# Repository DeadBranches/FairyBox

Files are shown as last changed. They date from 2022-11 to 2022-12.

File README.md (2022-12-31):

# FairyBox

Kicad_board_render

pcbnew_screenshot

### Software
A fork of [LilyTiny TinyTwinkle](https://github.com/deadbranch-forks/LilyTiny_LilyTwinkle)

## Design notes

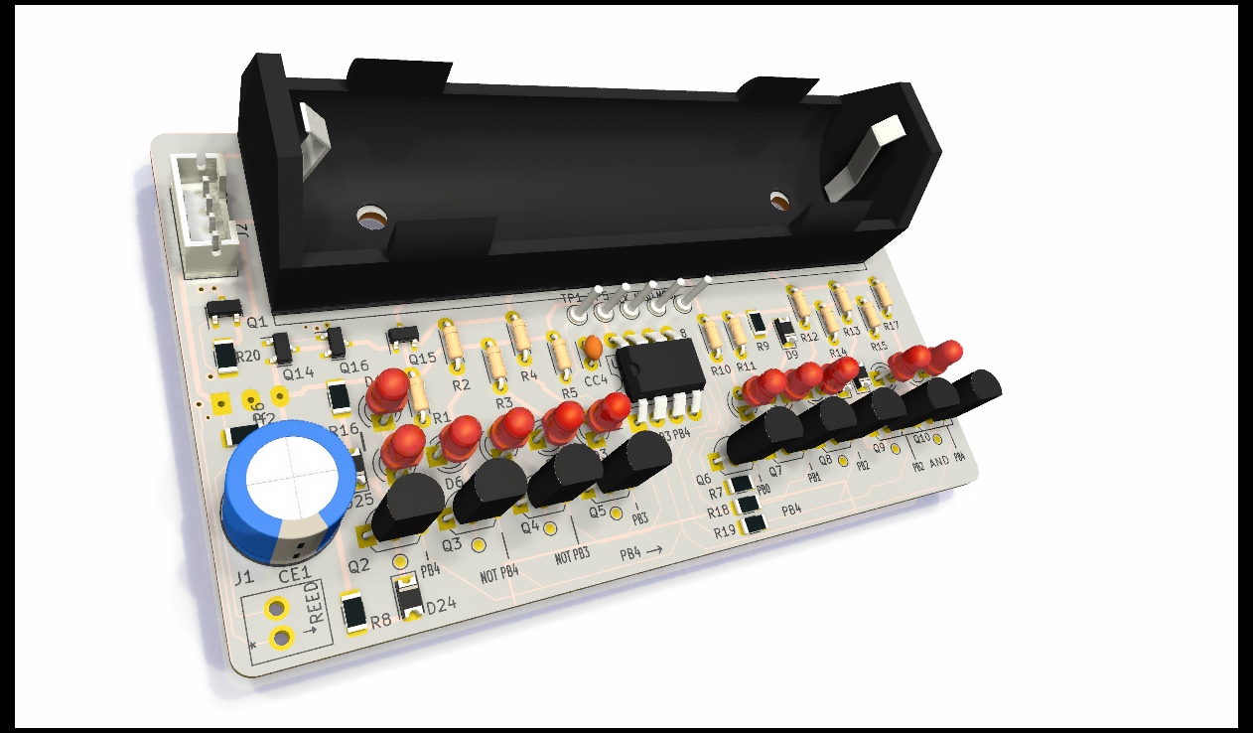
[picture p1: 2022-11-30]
Hardware/Fairybox-render-111022.png

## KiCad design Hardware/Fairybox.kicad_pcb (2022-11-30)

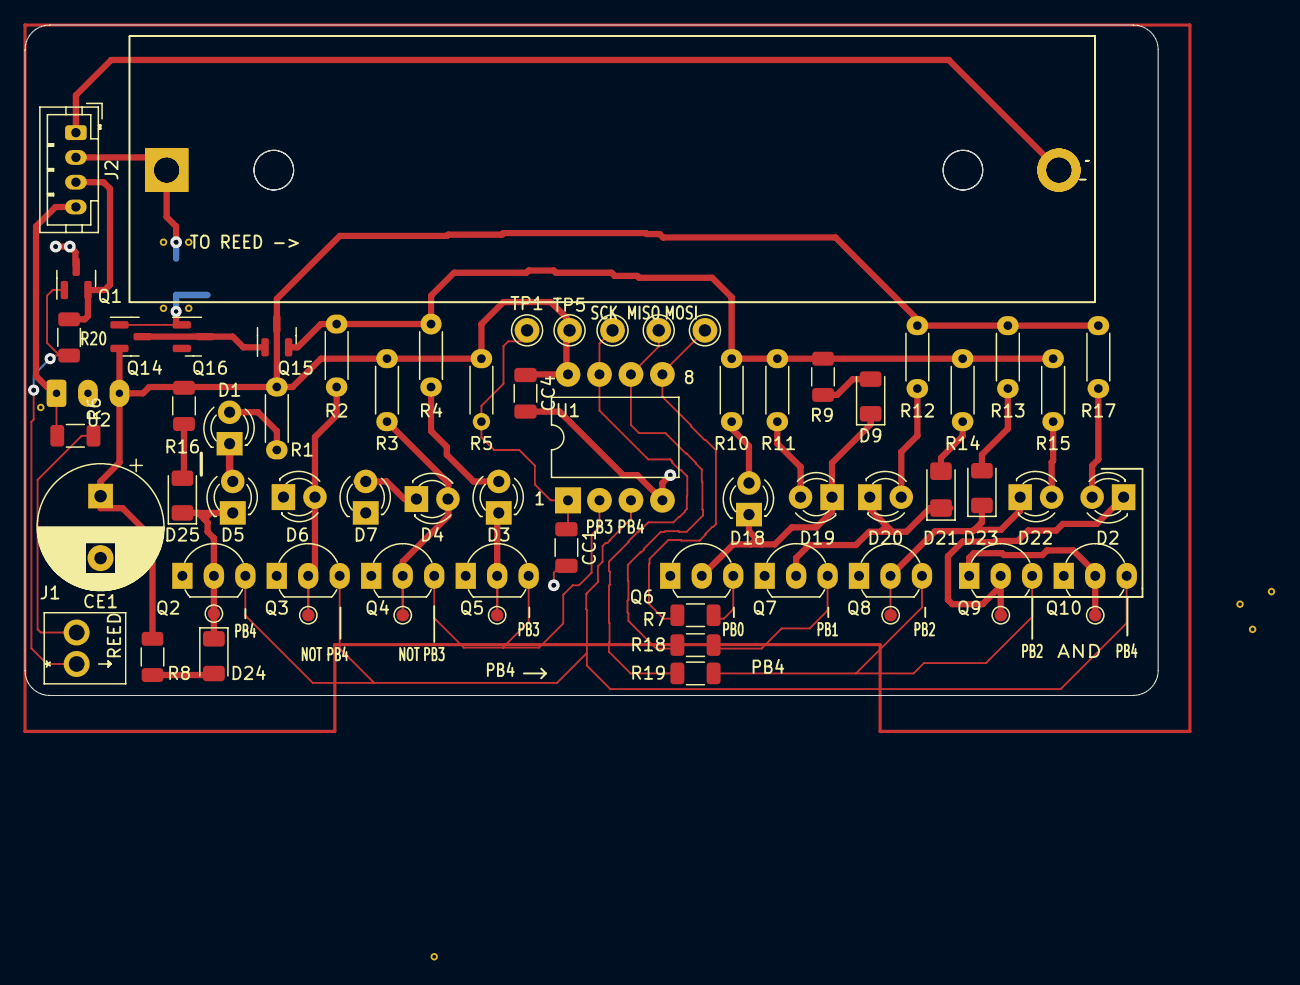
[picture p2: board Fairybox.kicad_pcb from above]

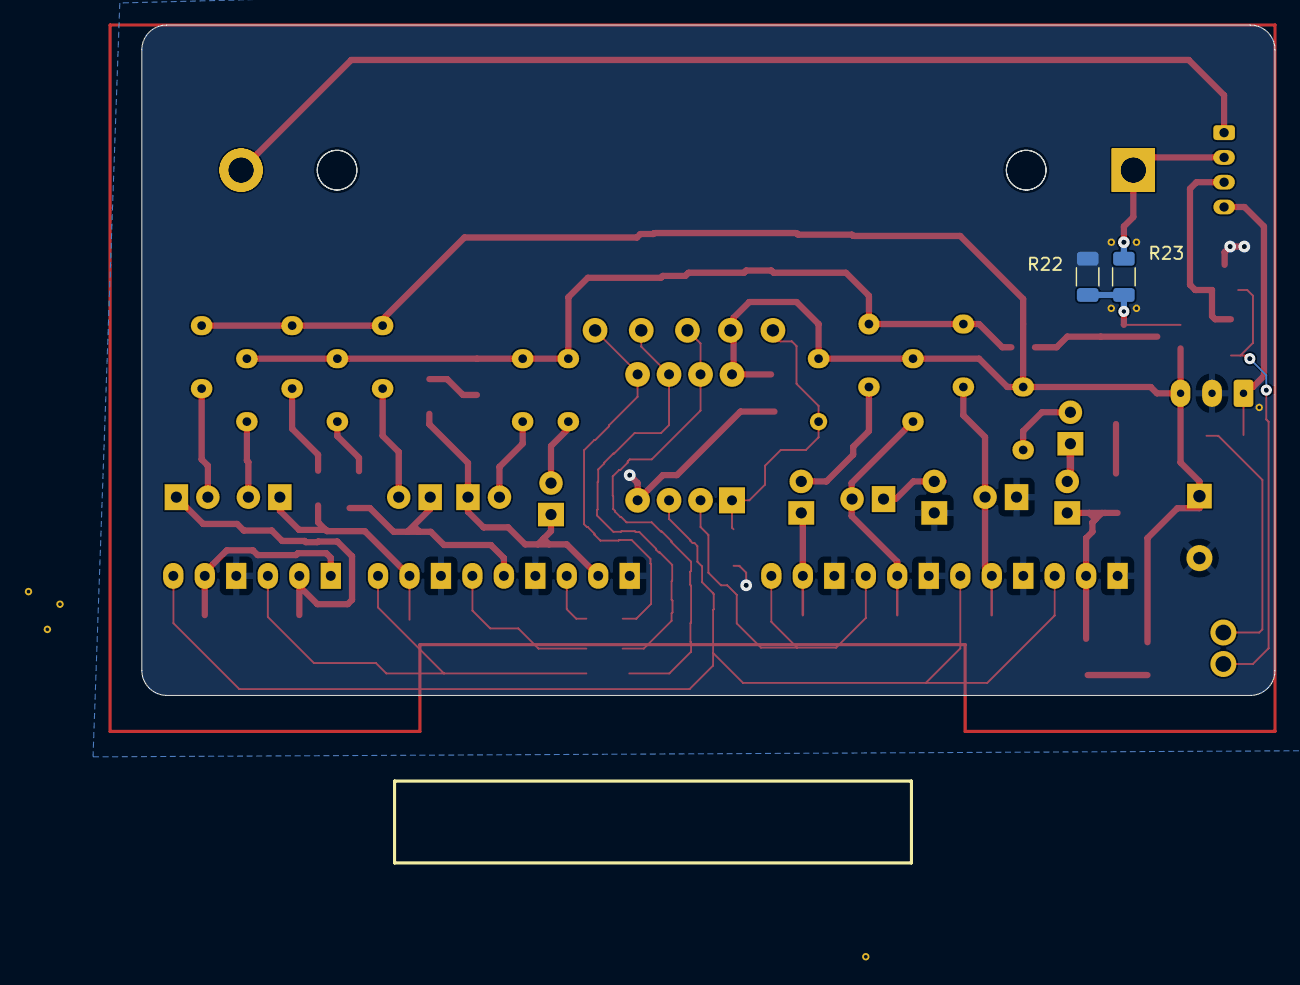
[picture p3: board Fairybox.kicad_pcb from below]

Board: 2 copper layers, 91.4 x 54.1 mm, 81 parts (2 on the bottom side), 43 nets.

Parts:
BAT1, BAT1#2: locked; 18650 battery sled 1x
CC1: 0.22uF; C_1206_3216Metric
CC4: locked; C_1206_3216Metric
CE1: locked; CP_Radial_D10.0mm_P5.00mm
D1, D2, D3, D5, D6, D7, D18, D19, D20, D22: locked; LED_D3.0mm-DRC-larger-silk-footprint
D4: RED; LED_D3.0mm-DRC-larger-silk-footprint
D9, D24: BLUE; D_1206_3216Metric
D21: BLUE; D_1206_3216Metric_Pad1.42x1.75mm_HandSolder
D23, D25: RED; D_1206_3216Metric
J1: REED; KF128-2P
J2: JST B4B-PH-K-S; JST_PH_B4B-PH-K_1x04_P2.00mm_Vertical
JP1, JP3, JP5, JP9: ViaGND; Via-GND
JP2, JP4, JP6, JP7, JP8: ViaGND; PTH-Test_Point
Q1: locked; SOT-23
Q2, Q3, Q4, Q5, Q6, Q7, Q8, Q9, Q10: locked; TO-92L_Inline_Wide
Q14: AO3401A; SOT-23
Q15, Q16: SI2302; SOT-23
R1, R2, R3, R4, R5, R10, R11, R12, R13, R14, R15, R17: locked; R_Axial_DIN0204_L3.6mm_D1.6mm_P5.08mm_Horizontal
R6: 10K; R_1206_3216Metric
R7, R8, R18, R19: 470R; R_1206_3216Metric
R9: ??R; R_1206_3216Metric
R16: locked; R_1206_3216Metric
R20: 100K; R_1206_3216Metric
R22: 1M; R_1206_3216Metric
R23: 330k; R_1206_3216Metric
TP1: RST; Pin_D1.0mm_L10.0mm
TP2: locked; Pin_D1.0mm_L10.0mm
TP3: MISO; Pin_D1.0mm_L10.0mm
TP4: MOSI; Pin_D1.0mm_L10.0mm
TP5: VCC; Pin_D1.0mm_L10.0mm
TP6: TPP; TestPoint_Pad_D1.0mm
TP7: Q3_COL TP; TestPoint_Pad_D1.0mm
TP8: Q2_TP; TestPoint_Pad_D1.0mm
TP9: Q5_COL TP; TestPoint_Pad_D1.0mm
TP10: Q8_COL_TP; TestPoint_Pad_D1.0mm
TP11: Q9_COL_TP; TestPoint_Pad_D1.0mm
TP12: Q10_COL_TP; TestPoint_Pad_D1.0mm
U1: ATTINY85; DIP-8_W10.16mm
U2: locked; 3p-P2.54mm-big-pad-wire-holes

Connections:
+5V: CC4.1, CE1.1, Q14.2 (S), Q15.3 (D), R1.1, R3.1, R5.2, R8.1, R12.1, R13.1, R16.1, R17.1, TP5.1, U1.8 (VCC), U2.3 (VOUT)
/+5V B-LED: Q15.2 (S), R2.1, R4.1, R9.1, R10.1, R11.1, R14.1, R15.1
/CHARGE BOARD OUT B+: J2.4, R6.2, U2.1 (VIN)
/CHARGE BOARD OUT B-: J2.3, Q1.2 (S), R20.1
/D1_AN: D1.2 (A), R1.2
/D2_AN: D2.2 (A), R17.2
/D3_AN: D3.2 (A), R4.2
/D5_AN: D1.1 (K), D5.2 (A)
/D6_AN: D6.2 (A), Q3.2 (C), R2.2, TP7.1
/D7_AN: D4.1 (K), D7.2 (A)
/D9_AN: D9.2 (A), R9.2
/D18_AN: D18.2 (A), R10.2
/D19_AN: D19.2 (A), R11.2
/D20_AN: D20.2 (A), R12.2
/D21_AN: D22.2 (A), R15.2
/D22_AN: D21.2 (A), R14.2
/D23_AN: D23.2 (A), R13.2
/D24_AN: D24.2 (A), R8.2
/D25_AN: D25.2 (A), R16.2
/LBAT_NOT: Q14.1 (G), Q16.1 (G), R22.1, R23.2
/LI-ION_NEG: BAT1.2 (-), BAT1#2.2 (-), J2.2
/LI-ION_POS: BAT1.1 (+), BAT1#2.1 (+), J2.1, R22.2
/MCU GPIO0 MOSI: Q6.3 (B), R7.2
/MCU GPIO1 MISO: Q7.3 (B), R18.2
/MCU GPIO2 SCK: Q8.3 (B), Q9.3 (B), R19.2
/MCU GPIO3: Q4.3 (B), Q5.3 (B), U1.2 (PB3)
/MCU GPIO4: Q2.3 (B), Q3.3 (B), Q10.3 (B), U1.3 (PB4)
/MCU RST: CC1.1, R5.1, TP1.1, U1.1 (RST)
/PB0 PHY: R7.1, TP4.1, U1.5 (PB0)
/PB1 PHY: R18.1, TP3.1, U1.6 (PB1)
/PB2 PHY: R19.1, TP2.1, U1.7 (PB2)
/Q1_GATE: J1.2, Q1.1 (G), R20.2
/Q2_COL: D5.1 (K), D24.1 (K), D25.1 (K), Q2.2 (C), TP8.1
/Q4_COL: D4.2 (A), Q4.2 (C), R3.2, TP6.1
/Q5_COL: D3.1 (K), Q5.2 (C), TP9.1
/Q6_COL: D9.1 (K), D18.1 (K), D19.1 (K), Q6.2 (C)
/Q7_COL: D20.1 (K), D21.1 (K), Q7.2 (C)
/Q8_COL: D22.1 (K), D23.1 (K), Q8.2 (C), TP10.1
/Q9_COL: D2.1 (K), Q9.2 (C), TP11.1
/Q10_COL: Q9.1 (E), Q10.2 (C), TP12.1
/Q15_COL: Q14.3 (D), Q15.1 (G), Q16.3 (D)
/REED_IN: J1.1, R6.1
GND: CC1.2, CC4.2, CE1.2, D6.1 (K), D7.1 (K), JP1.1 (GND), JP2.1 (GND), JP3.1 (GND), JP4.1 (GND), JP5.1 (GND), JP6.1 (GND), JP7.1 (GND), JP8.1 (GND), JP9.1 (GND), Q1.3 (D), Q2.1 (E), Q3.1 (E), Q4.1 (E), Q5.1 (E), Q6.1 (E), Q7.1 (E), Q8.1 (E), Q10.1 (E), Q16.2 (S), R23.1, U2.2 (GND)

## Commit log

2022-10-16 GPIO Assignment Changes
    In order to enable more efficient signal trace routing transistor base pins were reassigned to different MCU signal pins. The new order no longer has signal traces crossing paths to get to their destination. In other words, it's eliminated the need for any vias to the ground plane.
    This routing is much simpler and improves the chances of a successful (functioning) PCB.
    - Easier to manufacture. Not pushing JLCPCB's manufacturing capabilities is a good thing.
    - Likely less unintended EMI radiation.
    - Less opportunities for signal crosstalk.
    [fairybox.kicad_sch]
2022-10-16 MCU reset pin and resistor fix
    Attiny85 Reset Pin
    - Rotated pull-up resistor R5. 5V pad now faces north.
    - Extended 5V copper pour to include R5
    [fairybox.kicad_pcb]
2022-10-16 Eliminating Q10_COL via
    Re-routed Q9_COL around Q9 to eliminate the need for the Q10_COL net via.
    [fairybox.kicad_pcb]
2022-10-16 Removed bulk capacitor power puddle
    Replaced CE1<>U2 copper pour with a 0.600mm track.
    [fairybox.kicad_pcb]
2022-10-17 Updated solder mask labels
    Moved component reference designators around. Added some informational text to the solder mask
    [fairybox.kicad_pcb]
2022-10-19 Cleanup
    alignment and other misc changes.
    [fairybox.kicad_pcb]
2022-10-19 Adding kicad project files
    [Fairybox.kicad_pcb, Fairybox.kicad_sch]
2022-10-19 Testing kicad/github interoperability
    [Fairybox.kicad_sch]
2022-10-19 Testing kicad/github interoperability v2
    [Fairybox.kicad_sch]
2022-10-20 Testing how symlinks interact with git. FairyBoxTest.ino is a symlink to the ArduinoIDE sketch folder elsewhere on the drive.
2022-10-20 testing symlinks. Updated /f/c/code - arduino sketchbooks/fairybox - branch_main/fairybox - branch_main.ino with a comment. Seeing if giit picks it up.
2022-10-21 Testing git and ArduinoIDE links. File in arduino sketch folder is a symlink to local git repo. With ArduinoIDE, opened sketch, made a change, saved. Git picked up the change. Pushing it to remote re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
2022-10-21 Misc changes I forget
    [Fairybox.kicad_pcb, Fairybox.kicad_sch]
2022-10-21 Removing relocated kicad project files.
    [fairybox.kicad_pcb, fairybox.kicad_sch]
2022-10-24 Misc hardware changes
    [Fairybox.kicad_pcb, Fairybox.kicad_sch]
2022-10-24 Update Fairybox.kicad_pro
    Sync with local
2022-10-24 Update Fairybox.kicad_sch
    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
    [Fairybox.kicad_sch]
2022-10-25 Updated testpoints and silkscreen
    [Fairybox.kicad_pcb, Fairybox.kicad_sch]
2022-10-27 PCB layout tweaks
    [Fairybox.kicad_pcb]
2022-10-28 Power Delivery EEschema - Added two 1x2P 2.5mm pitch pin header symbols with associated footprints to replace the custom liion charge breakout board symbol/footprints - Moved liion charge board and n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
    MCU
    EEschema
    - Added 220R series resistors (R7, R18, R19) to each MCU pin used for SPI in circuit programming. Protects the programmer GPIO pins from voltages greater than 22mA
    PCBnew
    - 220R series resistors added to SPI lines at the bottom of the board. Sh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
    [Fairybox.kicad_pcb, Fairybox.kicad_sch]
2022-10-31 JST connector, Rule Zone Added JST PH connector instead of screw terminals. Corrected keepout zone.
    [Fairybox.kicad_pcb, Fairybox.kicad_sch]
2022-10-31 Rolling back some changes.
    [Fairybox.kicad_pcb]
2022-11-12 a lot
    [Fairybox.kicad_pcb, Fairybox.kicad_sch]
2022-11-13 Edge cut.
    [Fairybox.kicad_pcb]
2022-11-30 not sure
    [Fairybox.kicad_pcb, Fairybox.kicad_sch]
